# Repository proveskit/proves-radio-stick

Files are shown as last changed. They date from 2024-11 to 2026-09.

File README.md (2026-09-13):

# proves-radio-stick
New repo for working on a USB stick sized LoRa radio module. 

# Design Purpose
Being able to send and receive data using radios is one of the most fundemental functionalities of the satellite system. Right now, if we want to do anything with the radios we need to take a whole flight controller board out and get it setup to send and receive data. It would be nice to have an [RTL-SDR Style](https://www.rtl-sdr.com/buy-rtl-sdr-dvb-t-dongles/) USB dongle that can be used for testing and ground station purposes! 

# Design Requirements
- Employs an RP2040 Microcontroller (V0); RP2350 from V1 onward
- Onboard 3.3 V regulator for the microcontroller (LDO on V0, TPS62085 buck from V1); V2 radio runs from 5 V VBUS via ferrite
- Radio module: RFM9XW slot (V0), EByte E32-400M20S (V1), EByte E22-400M30S (V2)
- SMA Adaptor for the Antenna
- Is as comapct as possible 

# Versions
| Dir | MCU | Radio | Rail | Antenna | Notes |
|---|---|---|---|---|---|
| `provesradiostick_V0` | RP2040 | RFM9XW slot (SX127x) | 3V3 LDO | SMA | Original concept |
| `proves_radio_stick_V1` | RP2350 | EByte E32-400M20S (SX1278, 20 dBm) | 3V3 buck (TPS62085) | SMA | 4-layer 60 x 32.89 mm |
| `proves_radio_stick_V2` | RP2350 | EByte E22-400M30S (SX1268, 30 dBm) — same module as FC v5e | 3V3 buck + 5 V `RF_VCC` from VBUS via ferrite | SMA | 4-layer 80.5 x 32.89 mm; V1 stretched 20.5 mm to fit the 24 x 38.5 mm module |

## V2 radio pinout (RP2350 GPIO)
| E22 pin | Net | GPIO |
|---|---|---|
| NSS / SCK / MOSI / MISO | SPI1_CS0 / SPI1_SCK / SPI1_MOSI / SPI1_MISO | 9 / 10 / 11 / 8 |
| NRST | RF1_RST | 6 |
| BUSY | RF1_IO0 | 14 |
| DIO1 | RF1_IO1 | 15 |
| DIO2 | RF1_IO2 | 16 |
| RXEN / TXEN | RF1_RX_EN / RF1_TX_EN | 20 / 21 |
| VCC | RF_VCC (5 V, VBUS → FB1 → U19 TPS22918 load switch) | — |
| Radio power enable | RF_PWR_EN → U19 ON (10k pull-up to 3V3, default ON) | 18 |

V2 note: at 30 dBm the E22 draws ~650 mA peak on TX, above the 500 mA USB 2.0 default; use a USB 3 or high-current port for sustained TX. The 110 µF behind U19 soft-starts over ~3 ms (CT 1 nF, ~0.19 A inrush) so the host only sees ~11 µF at plug-in. Drive GPIO18 low then high to power-cycle the radio (hold NRST low and SPI lines low while off). V2 drops the 2.54 mm SWD pin header J1; use the JST-SH SWD connector J22. J3 screw terminal is sourced as Cixi Kefa KF128-2.54-10P (LCSC C474928), a 2.54 mm drop-in for the Phoenix MPT 0,5/10-2,54 footprint. J4 header and TP1–TP7 are not populated by JLC. Firmware differs from V1: SX1268 driver with BUSY handshake, not SX1278. Pin numbering differs from FC v5e (v5e uses SPI0 GPIO9-12, BUSY 13, DIO1 14, RXEN 22).

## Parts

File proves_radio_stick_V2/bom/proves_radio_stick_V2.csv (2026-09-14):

Ref | Value | Footprint | LCSC | Qty
C1,C2,C67,C70-C74,C76-C78 | 100n | Capacitor_SMD:C_0402_1005Metric | C1525 | 11
C3 | 47uF | Capacitor_SMD:C_0805_2012Metric | C16780 | 1
C4 | 100uF 10V | Capacitor_SMD:C_1210_3225Metric | C84455 | 1
C5,C15 | 10uF | Capacitor_SMD:C_0603_1608Metric | C19702 | 2
C6 | 100nF | Capacitor_SMD:C_0402_1005Metric | C1525 | 1
C7 | 100pF | Capacitor_SMD:C_0402_1005Metric | C1546 | 1
C14 | 22uF | Capacitor_SMD:C_0603_1608Metric | C59461 | 1
C63,C64 | 15p | Capacitor_SMD:C_0402_1005Metric | C1548 | 2
C65,C66 | 4.7u | RP2350_60QFN_minimal:C_0402_1005Metric_small_pads | C23733 | 2
C68,C69 | 4.7u | Capacitor_SMD:C_0402_1005Metric | C23733 | 2
C75 | 10u | Capacitor_SMD:C_0603_1608Metric | C19702 | 1
C79 | 1nF | Capacitor_SMD:C_0402_1005Metric | C1523 | 1
C80 | 1uF | Capacitor_SMD:C_0402_1005Metric | C52923 | 1
D1,D3 | LED | LED_SMD:LED_0603_1608Metric | C2290 | 2
D4 | NSR0320 | Diode_SMD:D_SOD-323F | C48192 | 1
FB1 | BLM21PG600SN1D | Inductor_SMD:L_0805_2012Metric | C18305 | 1
J2 | Conn_Coaxial | Connector_Coaxial:SMA_Amphenol_132134_Vertical | C3174425 | 1
J3 | Screw_Terminal_01x10 | TerminalBlock_Phoenix:TerminalBlock_Phoenix_MPT-0,5-10-2.54_1x10_P2.54mm_Horizontal | C474928 | 1
J12 | USB_C_Receptacle_USB2.0_16P | Connector_USB:USB_C_Receptacle_HRO_TYPE-C-31-M-12 | C165948 | 1
J22 | SWD Port | Connector_JST:JST_SH_BM03B-SRSS-TB_1x03-1MP_P1.00mm_Vertical | C160389 | 1
L1 | XFL4015-471MEC | easyeda2kicad:IND-SMD_L4.0-W4.0_XFL4020-102MEB | C18221164 | 1
L2 | 120nH | Inductor_SMD:L_0603_1608Metric | C86138 | 1
L3 | 3.3u | RP2350_60QFN_minimal:L_pol_2016 | C42411119 | 1
R1,R2,R5,R9,R11,R12,R39,R41,R95 | 10k | Resistor_SMD:R_0402_1005Metric | C25744 | 9
R3 | 162k | Resistor_SMD:R_0402_1005Metric | C54068 | 1
R4 | 510k | Resistor_SMD:R_0402_1005Metric | C11616 | 1
R7,R8 | 22 | Resistor_SMD:R_0402_1005Metric | C25092 | 2
R10,R13,R80,R93 | 1k | Resistor_SMD:R_0402_1005Metric | C11702 | 4
R14,R15 | 4.7k | Resistor_SMD:R_0402_1005Metric | C25900 | 2
R26,R27 | 5.1k | Resistor_SMD:R_0402_1005Metric | C25905 | 2
R94 | 33 | Resistor_SMD:R_0402_1005Metric | C25105 | 1
SW1,SW2 | KMR2 | FC_DEV_BOARD:BTN_KMR2_4.6X2.8 | C72443 | 2
U2 | TPS62085RLTT | easyeda2kicad:VSON-7_L2.0-W2.0-P0.5-TL | C2070694 | 1
U3 | E22-400M30S | easyeda2kicad:WIRELM-SMD_E22-400M30S | C411292 | 1
U11 | W25Q128JVS | Package_SO:SOIC-8_5.3x5.3mm_P1.27mm | C97521 | 1
U18 | RP2350_60QFN | RP2350_60QFN_minimal:RP2350-QFN-60-1EP_7x7_P0.4mm_EP3.4x3.4mm_ThermalVias | C42411118 | 1
U19 | TPS22918DBVR | Package_TO_SOT_SMD:SOT-23-6 | C131941 | 1
Y1 | ABM8-272-T3 | Crystal:Crystal_SMD_3225-4Pin_3.2x2.5mm | C20625731 | 1

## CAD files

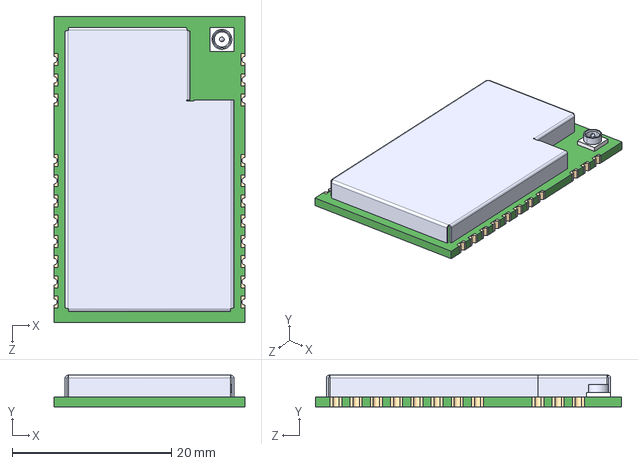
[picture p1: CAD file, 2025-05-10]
proves_radio_stick_V2/Backup_Footprints/E22-400M30S/E22-400M30S.step
24.0 x 3.97 x 38.5 mm

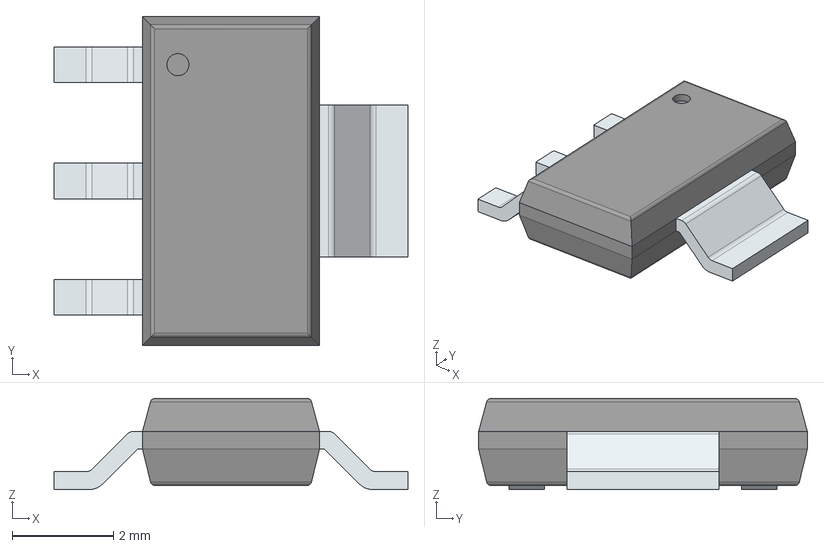
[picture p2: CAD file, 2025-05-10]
proves_radio_stick_V2/Backup_Footprints/LIB_AZ1117CH-3.3TRG1 (1)/AZ1117CH-3.3TRG1/3D/AZ1117CH-3.3TRG1.stp
7.00 x 6.50 x 1.80 mm
PinsArrayL
FilletPinR

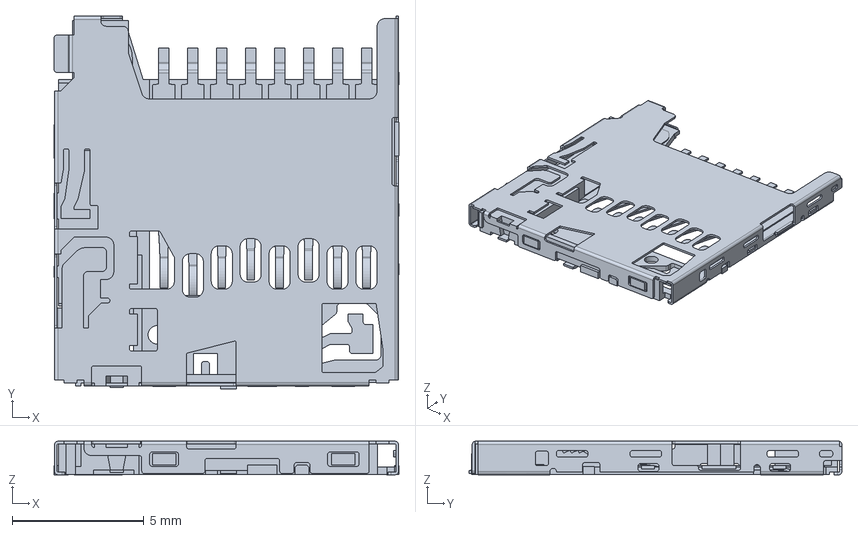
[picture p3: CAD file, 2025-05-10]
proves_radio_stick_V2/Backup_Footprints/Molex 503398-1892/503398-1892.stp
13.1 x 14.2 x 1.28 mm

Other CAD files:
proves_radio_stick_V2/Backup_Footprints/LIB_AZ1117CH-3.3TRG1 (1)/AZ1117CH-3.3TRG1/Allegro/sot230p700x180-4n.psm
proves_radio_stick_V2/Backup_Footprints/LIB_AZ1117CH-3.3TRG1 (1)/AZ1117CH-3.3TRG1/DEHDL/az1117ch_3.3trg1/chips/chips.prt

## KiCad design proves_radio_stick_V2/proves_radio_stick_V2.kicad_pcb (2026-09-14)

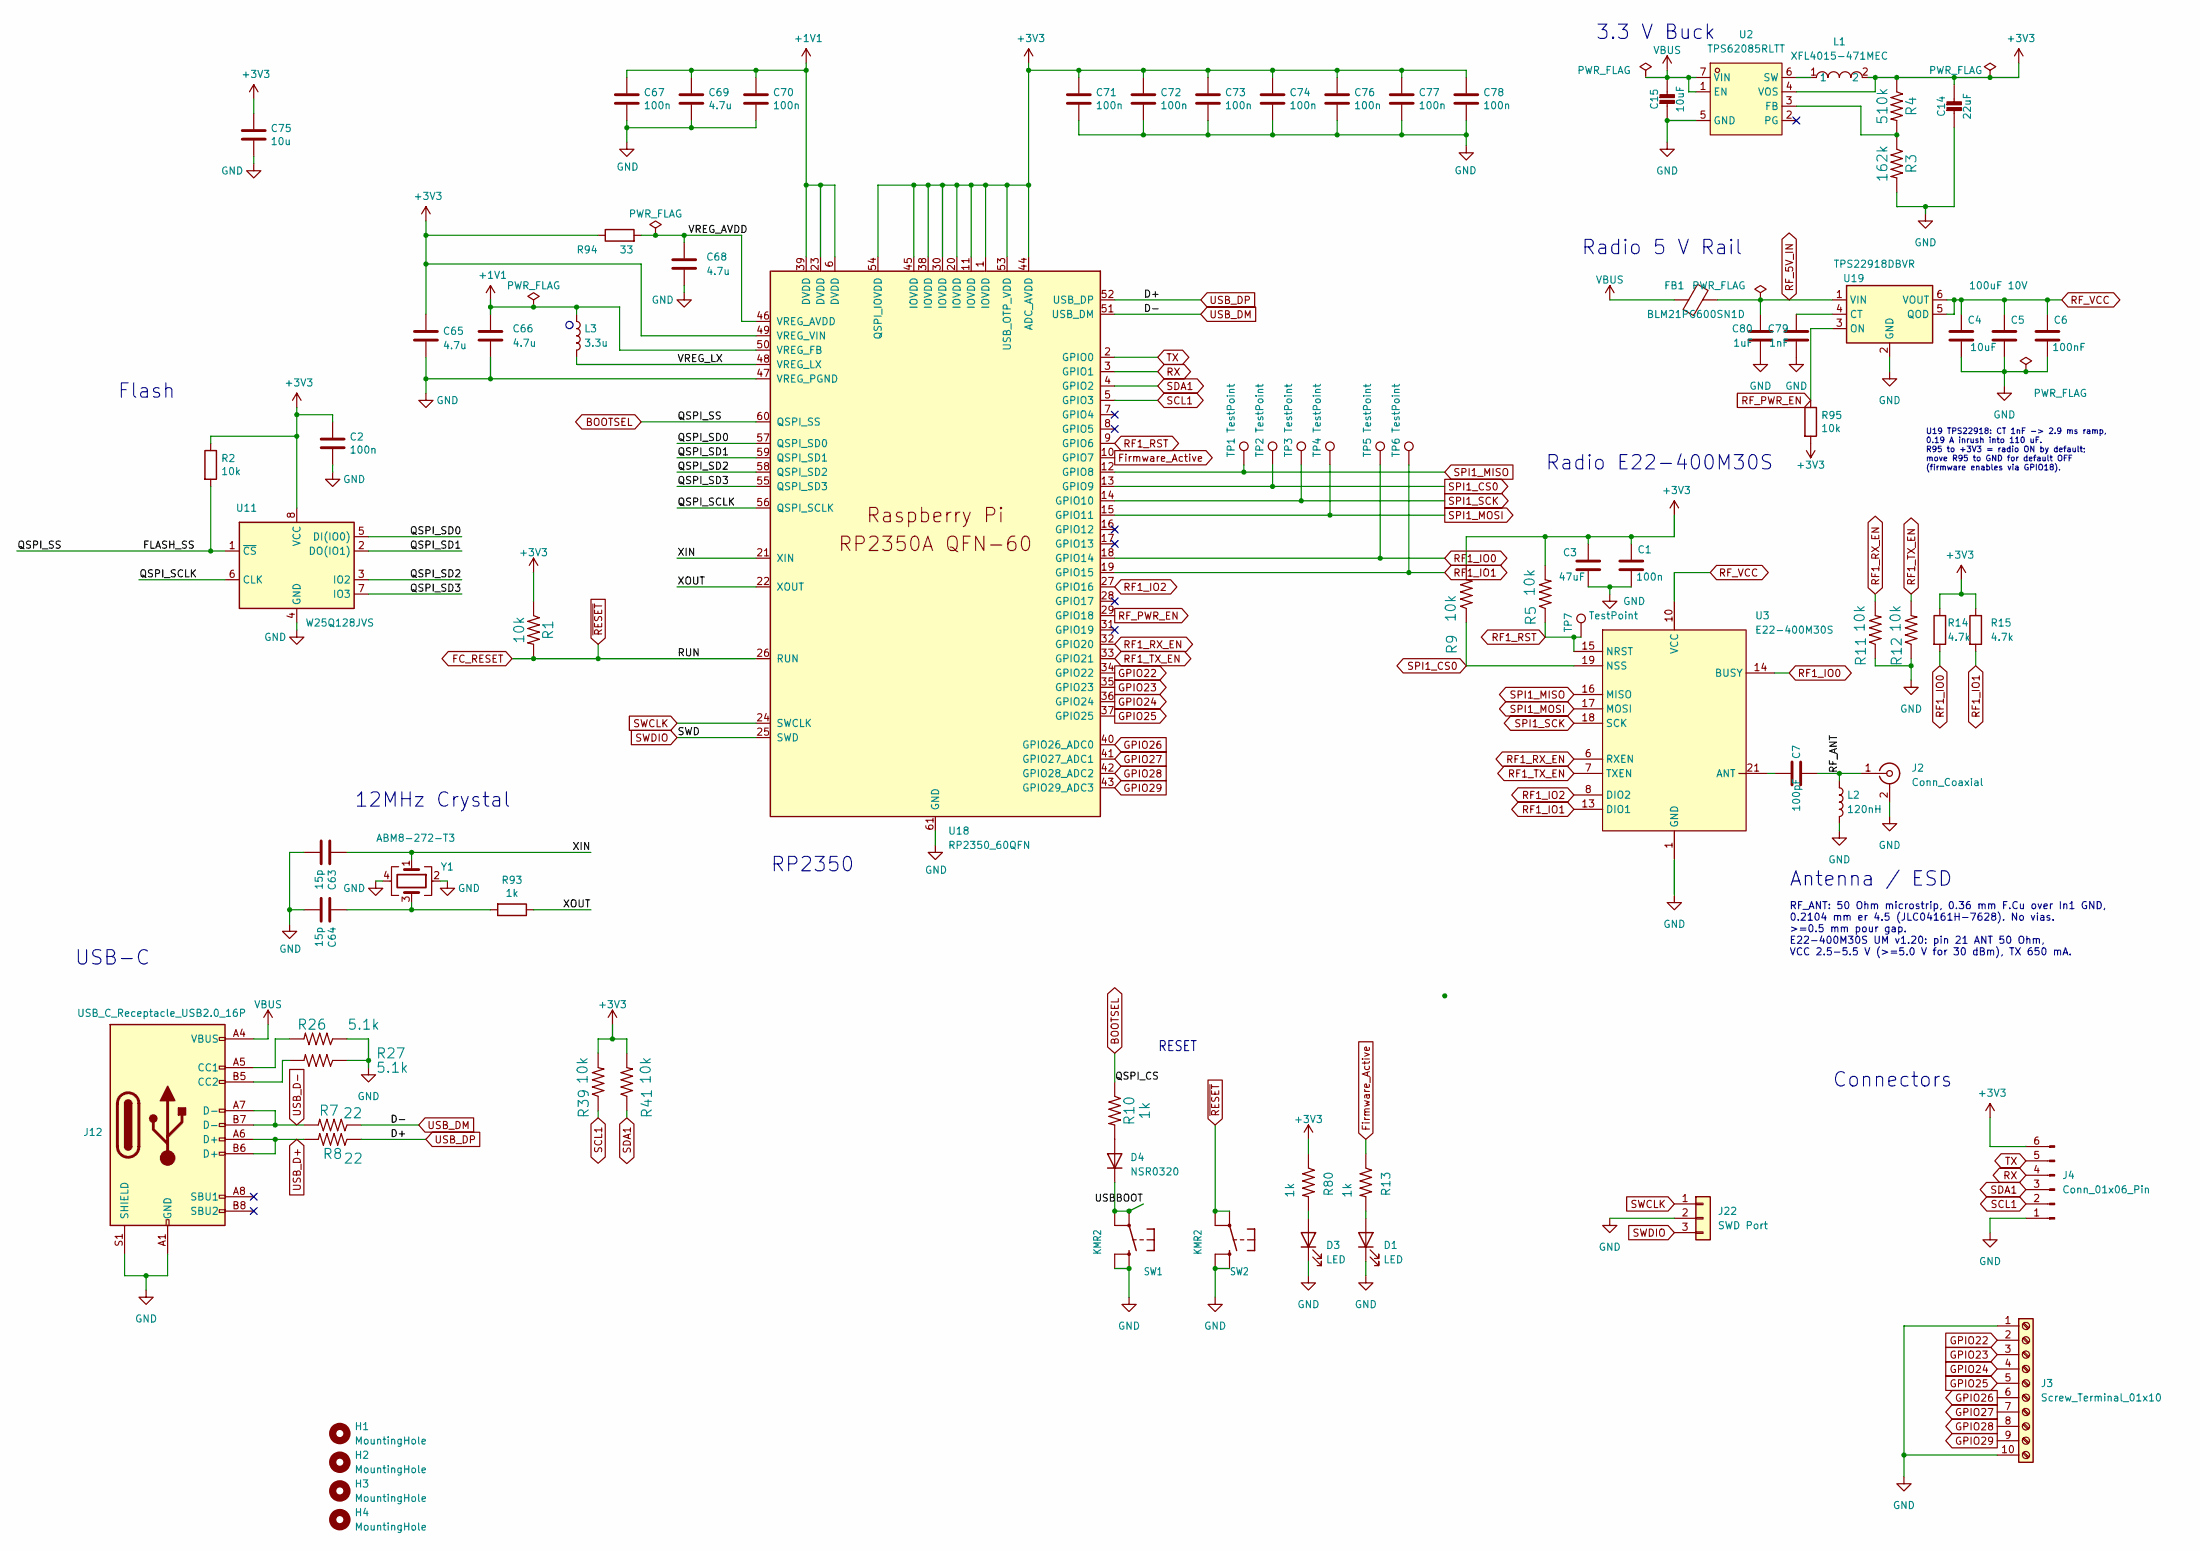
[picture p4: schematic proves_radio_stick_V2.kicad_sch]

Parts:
C1, C2, C67, C70, C71, C72, C73, C74, C76, C77, C78: 100n; C_0402_1005Metric; LCSC Part C1525
C3: 47uF; C_0805_2012Metric; LCSC Part C16780
C4: 100uF 10V; C_1210_3225Metric; LCSC Part C84455
C5, C15: 10uF; C_0603_1608Metric; LCSC Part C19702
C6: 100nF; C_0402_1005Metric; LCSC Part C1525
C7: 100pF; C_0402_1005Metric; LCSC Part C1546
C14: 22uF; C_0603_1608Metric; LCSC Part C59461
C63, C64: 15p; C_0402_1005Metric; LCSC Part C1548
C65, C66: 4.7u; C_0402_1005Metric_small_pads; LCSC Part C23733
C68, C69: 4.7u; C_0402_1005Metric; LCSC Part C23733
C75: 10u; C_0603_1608Metric; LCSC Part C19702
C79: 1nF; C_0402_1005Metric; LCSC Part C1523
C80: 1uF; C_0402_1005Metric; LCSC Part C52923
D1, D3: LED; LED_0603_1608Metric; LCSC Part C2290
D4: NSR0320; D_SOD-323F; LCSC Part C48192
FB1: BLM21PG600SN1D; L_0805_2012Metric; LCSC Part C18305
H1, H2, H3, H4: MountingHole; MountingHole_2.2mm_M2_Pad_TopBottom
J2: Conn_Coaxial; SMA_Amphenol_132134_Vertical; LCSC Part C3174425
J3: Screw_Terminal_01x10; TerminalBlock_Phoenix_MPT-0,5-10-2.54_1x10_P2.54mm_Horizont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; MPN KF128-2.54-10P; LCSC Part C474928
J4: Conn_01x06_Pin; PinHeader_1x06_P2.54mm_Vertical
J12: USB_C_Receptacle_USB2.0_16P; USB_C_Receptacle_HRO_TYPE-C-31-M-12; LCSC Part C165948
J22: SWD Port; JST_SH_BM03B-SRSS-TB_1x03-1MP_P1.00mm_Vertical; LCSC Part C160389
L1: XFL4015-471MEC; IND-SMD_L4.0-W4.0_XFL4020-102MEB; LCSC Part C18221164
L2: 120nH; L_0603_1608Metric; MPN LQW18ANR12G00D; LCSC Part C86138
L3: 3.3u; L_pol_2016; LCSC Part C42411119
R1, R2, R5, R9, R11, R12, R39, R41, R95: 10k; R_0402_1005Metric; LCSC Part C25744
R3: 162k; R_0402_1005Metric; LCSC Part C54068
R4: 510k; R_0402_1005Metric; LCSC Part C11616
R7, R8: 22; R_0402_1005Metric; LCSC Part C25092
R10, R13, R80, R93: 1k; R_0402_1005Metric; LCSC Part C11702
R14, R15: 4.7k; R_0402_1005Metric; LCSC Part C25900
R26, R27: 5.1k; R_0402_1005Metric; LCSC Part C25905
R94: 33; R_0402_1005Metric; LCSC Part C25105
SW1, SW2: KMR2; BTN_KMR2_4.6X2.8; LCSC Part C72443
TP1, TP2, TP3, TP4, TP5, TP6, TP7: TestPoint; TestPoint_Keystone_5000-5004_Miniature
U2: TPS62085RLTT; VSON-7_L2.0-W2.0-P0.5-TL; LCSC Part C2070694
U3: E22-400M30S; WIRELM-SMD_E22-400M30S; MPN E22-400M30S; LCSC Part C411292
U11: W25Q128JVS; SOIC-8_5.3x5.3mm_P1.27mm; LCSC Part C97521
U18: RP2350_60QFN; RP2350-QFN-60-1EP_7x7_P0.4mm_EP3.4x3.4mm_ThermalVias; LCSC Part C42411118
U19: TPS22918DBVR; SOT-23-6; LCSC Part C131941
Y1: ABM8-272-T3; Crystal_SMD_3225-4Pin_3.2x2.5mm; LCSC Part C20625731

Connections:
+1V1: C66.1, C67.1, C69.1, C70.1, L3.1, U18.6 (DVDD), U18.23 (DVDD), U18.39 (DVDD), U18.50 (VREG_FB)
+3V3: C1.1, C2.1, C3.1, C14.1, C65.1, C71.1, C72.1, C73.1, C74.1, C75.1, C76.1, C77.1, C78.1, J4.6, L1.2, R1.1, R2.1, R4.1, R5.2, R9.2, R14.1, R15.1, R39.2, R41.2, R80.1, R94.1, R95.2, U2.4 (VOS), U11.8 (VCC), U18.1 (IOVDD), U18.11 (IOVDD), U18.20 (IOVDD), U18.30 (IOVDD), U18.38 (IOVDD), U18.44 (ADC_AVDD), U18.45 (IOVDD), U18.49 (VREG_VIN), U18.53 (USB_OTP_VDD), U18.54 (QSPI_IOVDD)
/QSPI_SCLK: U11.6 (CLK), U18.56 (QSPI_SCLK)
/QSPI_SD0: U11.5 (DI(IO0)), U18.57 (QSPI_SD0)
/QSPI_SD1: U11.2 (DO(IO1)), U18.59 (QSPI_SD1)
/QSPI_SD2: U11.3 (IO2), U18.58 (QSPI_SD2)
/QSPI_SD3: U11.7 (IO3), U18.55 (QSPI_SD3)
/RF_ANT: C7.2, J2.1 (In), L2.1
/USBBOOT: D4.1 (K), SW1.A, SW1.A' (P1)
/VREG_AVDD: C68.1, R94.2, U18.46 (VREG_AVDD)
/VREG_LX: L3.2, U18.48 (VREG_LX)
/XIN: C63.1, U18.21 (XIN), Y1.1
/XOUT: R93.1, U18.22 (XOUT)
BOOTSEL: R2.2, R10.1, U11.1 (~CS), U18.60 (QSPI_SS)
FC_RESET: R1.2, SW2.A, SW2.A' (P1), U18.26 (RUN)
Firmware_Active: R13.1, U18.10 (GPIO7)
GND: C1.2, C2.2, C3.2, C4.2, C5.2, C6.2, C14.2, C15.2, C63.2, C64.2, C65.2, C66.2, C67.2, C68.2, C69.2, C70.2, C71.2, C72.2, C73.2, C74.2, C75.2, C76.2, C77.2, C78.2, C79.2, C80.2, D1.1 (K), D3.1 (K), J2.2 (Ext), J3.1, J3.10, J4.1, J12.A1 (GND), J12.A12 (GND), J12.B1 (GND), J12.B12 (GND), J12.S1 (SHIELD), J22.2, L2.2, R3.2, R11.1, R12.1, R26.1, R27.1, SW1.B (S), SW1.B' (S1), SW2.B (S), SW2.B' (S1), U2.5 (GND), U3.1 (GND), U3.2 (GND), U3.3 (GND), U3.4 (GND), U3.5 (GND), U3.11 (GND), U3.12 (GND), U3.20 (GND), U3.22 (GND), U11.4 (GND), U18.47 (VREG_PGND), U18.61 (GND), U19.2 (GND), Y1.2, Y1.4
GPIO22: J3.2, U18.34 (GPIO22)
GPIO23: J3.3, U18.35 (GPIO23)
GPIO24: J3.4, U18.36 (GPIO24)
GPIO25: J3.5, U18.37 (GPIO25)
GPIO26: J3.6, U18.40 (GPIO26_ADC0)
GPIO27: J3.7, U18.41 (GPIO27_ADC1)
GPIO28: J3.8, U18.42 (GPIO28_ADC2)
GPIO29: J3.9, U18.43 (GPIO29_ADC3)
unnamed: C64.1, R93.2, Y1.3
unnamed: D1.2 (A), R13.2
unnamed: D3.2 (A), R80.2
unnamed: D4.2 (A), R10.2
unnamed: J12.A5 (CC1), R26.2
unnamed: J12.B5 (CC2), R27.2
unnamed: R3.1, R4.2, U2.3 (FB)
unnamed: L1.1, U2.6 (SW)
unnamed: C7.1, U3.21 (ANT)
unnamed: C79.1, U19.4 (CT)
RF1_IO0: R14.2, TP5.1, U3.14 (BUSY), U18.18 (GPIO14)
RF1_IO1: R15.2, TP6.1, U3.13 (DIO1), U18.19 (GPIO15)
RF1_IO2: U3.8 (DIO2), U18.27 (GPIO16)
RF1_RST: R5.1, TP7.1, U3.15 (NRST), U18.9 (GPIO6)
RF1_RX_EN: R11.2, U3.6 (RXEN), U18.32 (GPIO20)
RF1_TX_EN: R12.2, U3.7 (TXEN), U18.33 (GPIO21)
RF_5V_IN: C80.1, FB1.2, U19.1 (VIN)
RF_PWR_EN: R95.1, U18.29 (GPIO18), U19.3 (ON)
RF_VCC: C4.1, C5.1, C6.1, U3.9 (VCC), U3.10 (VCC), U19.5 (QOD), U19.6 (VOUT)
RX: J4.4, U18.3 (GPIO1)
SCL1: J4.2, R39.1, U18.5 (GPIO3)
SDA1: J4.3, R41.1, U18.4 (GPIO2)
SPI1_CS0: R9.1, TP2.1, U3.19 (NSS), U18.13 (GPIO9)
SPI1_MISO: TP1.1, U3.16 (MISO), U18.12 (GPIO8)
SPI1_MOSI: TP4.1, U3.17 (MOSI), U18.15 (GPIO11)
SPI1_SCK: TP3.1, U3.18 (SCK), U18.14 (GPIO10)
SWCLK: J22.1, U18.24 (SWCLK)
SWDIO: J22.3, U18.25 (SWD)
TX: J4.5, U18.2 (GPIO0)
USB_D+: J12.A6 (D+), J12.B6 (D+), R8.2
USB_D-: J12.A7 (D-), J12.B7 (D-), R7.2
USB_DM: R7.1, U18.51 (USB_DM)
USB_DP: R8.1, U18.52 (USB_DP)
VBUS: C15.1, FB1.1, J12.A4 (VBUS), J12.A9 (VBUS), J12.B4 (VBUS), J12.B9 (VBUS), U2.1 (EN), U2.7 (VIN)

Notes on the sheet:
RESET
Flash
12MHz Crystal
RF_ANT: 50 Ohm microstrip, 0.36 mm F.Cu over In1 GND, 0.2104 mm er 4.5 (JLC04161H-7628). No vias. >=0.5 mm pour gap. E22-400M30S UM v1.20: pin 21 ANT 50 Ohm, VCC 2.5-5.5 V (>=5.0 V for 30 dBm), TX 650 mA.
U19 TPS22918: CT 1nF -> 2.9 ms ramp, 0.19 A inrush into 110 uF. R95 to +3V3 = radio ON by default; move R95 to GND for default OFF (firmware enables via GPIO18).
3.3 V Buck
Radio 5 V Rail
Radio E22-400M30S
Antenna / ESD
Connectors
USB-C
RP2350

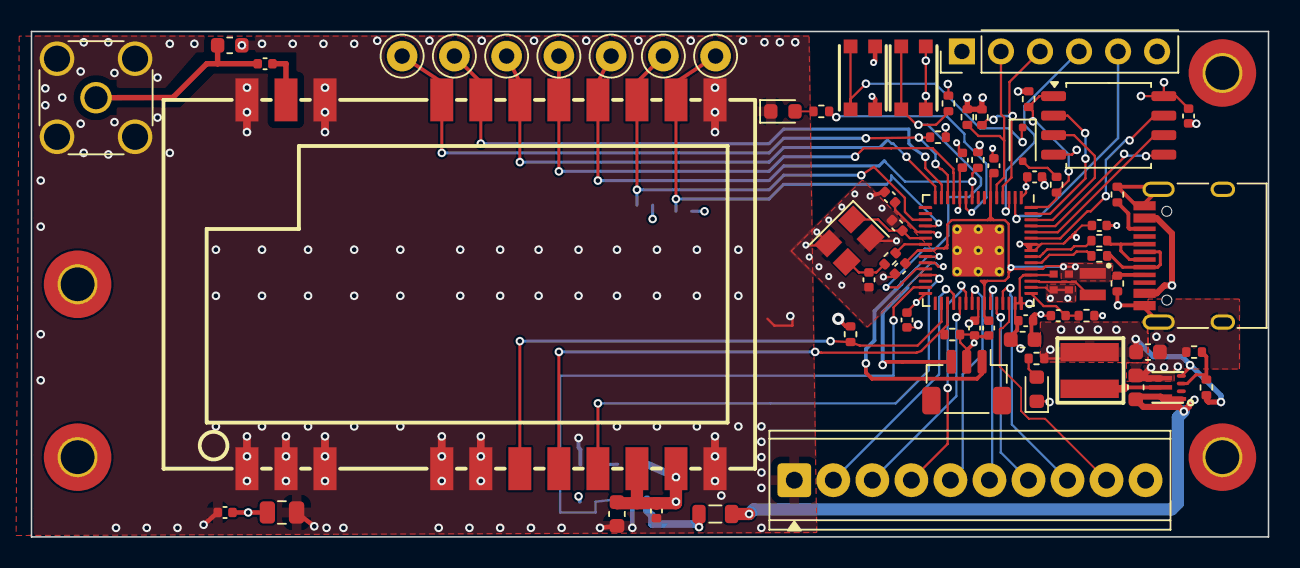
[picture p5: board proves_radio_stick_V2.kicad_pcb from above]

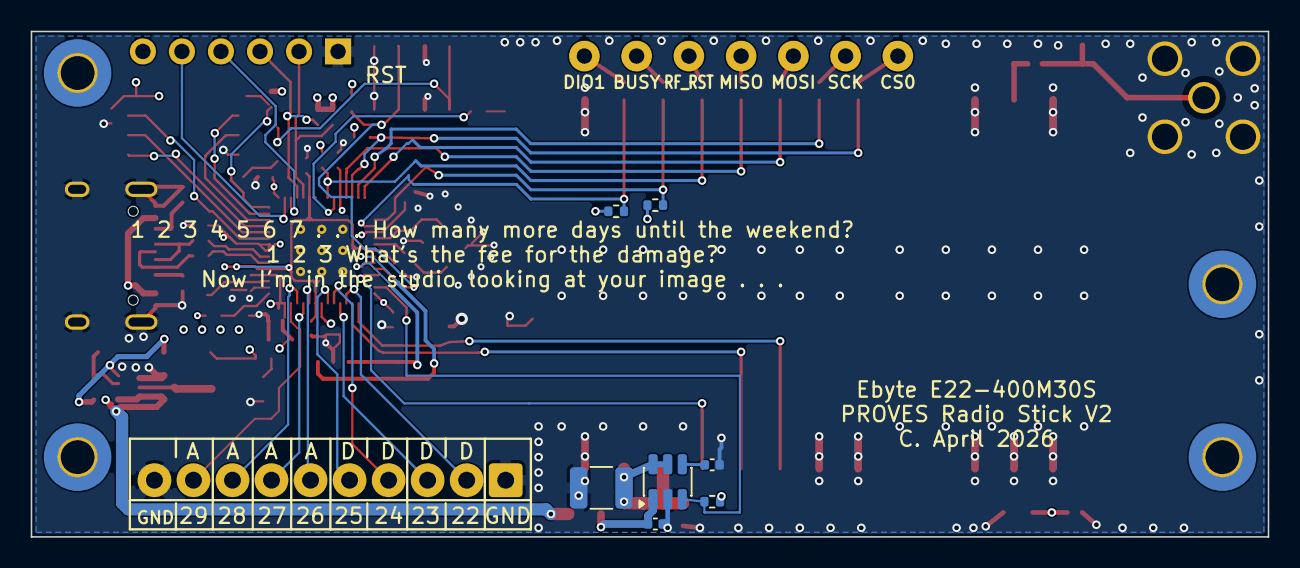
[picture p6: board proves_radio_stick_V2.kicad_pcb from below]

Board: 4 copper layers, 80.5 x 32.9 mm, 80 parts (7 on the bottom side), 59 nets.

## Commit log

2025-03-18 Created V0a Project
    [proves_radio_stick_V0a.kicad_pcb, proves_radio_stick_V0a.kicad_sch]
2025-05-09 Removed Unused Files
    [provesradiostick_V0.kicad_sch]
2025-05-10 Created Radio Stick V1 Project
    [503398-1892.stp, AZ1117CH-3.3TRG1.SchLib, AZ1117CH-3.3TRG1.stp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]
2025-06-15 Removed V0a Project
    [proves_radio_stick_V0a.kicad_pcb, proves_radio_stick_V0a.kicad_sch, proves_radio_stick_V1.kicad_pcb]
2025-10-04 Added E22-400M
    [proves_radio_stick_V1.kicad_sch]
2025-10-05 Initial TPS62 Layout
    [proves_radio_stick_V1.kicad_pcb, proves_radio_stick_V1.kicad_sch]
2025-10-05 Removed 3v3 Linear Regulator
    [proves_radio_stick_V1.kicad_pcb, proves_radio_stick_V1.kicad_sch]
2026-04-17 RP2350 and Support Circuits Layout
    [proves_radio_stick_V1.kicad_pcb, proves_radio_stick_V1.kicad_sch]
2026-04-17 Added E32 Footprint
    [proves_radio_stick_V1.kicad_pcb, proves_radio_stick_V1.kicad_sch]
2026-04-17 Initial Layout Complete
    [proves_radio_stick_V1.kicad_pcb, proves_radio_stick_V1.kicad_sch]
2026-04-17 Initial Production Files
    [proves_radio_stick_V1-CuBottom.gbr, proves_radio_stick_V1-CuIn1.gbr, proves_radio_stick_V1-CuIn2.gbr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]
2026-04-17 Updated DRC
    [proves_radio_stick_V1.kicad_pcb]
2026-04-21 Updated with Screw Terminals and Vias
    [proves_radio_stick_V1-CuBottom.gbr, proves_radio_stick_V1-CuIn1.gbr, proves_radio_stick_V1-CuIn2.gbr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]
2026-04-21 Updated Prod Files
    [proves_radio_stick_V1-CuBottom.gbr, proves_radio_stick_V1-CuIn1.gbr, proves_radio_stick_V1-CuIn2.gbr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]
2026-09-13 Create proves_radio_stick_V2 with EByte E22-400M30S
    V1 layout with the radio swapped to the E22-400M30S (SX1268, 30 dBm),
    the same module used on FC v5e. Board stretched to 80.5 x 32.89 mm to
    fit the 24 x 38.5 mm module.
    - New 5 V RF_VCC rail: VBUS -> FB1 -> 100u/10u/100n at module VCC pads
    - BUSY on GPIO14, DIO1 GPIO15, DIO2 GPIO16; SPI1/RST/RXEN/TXEN as V1
    - RF: 0.36 mm 50 ohm microstrip, RF netclass, ESD shunt L2 + DC block C7
    - Grounding: solid pad connects, in-pad vias, launch fence, B.Cu pour
    - easyeda2kicad symbols/footprints/3D now project-local
    - JLC production files with paste layers and filled zones
    - README: versions table, V2 pinout, USB current note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
    [503398-1892.stp, AZ1117CH-3.3TRG1.SchLib, AZ1117CH-3.3TRG1.stp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]
2026-09-13 V2: add TPS22918 soft-start switch on RF_VCC, drop J1
    Limits USB plug-in inrush: the 110 uF radio bulk now sits behind U19
    (CT 1 nF, ~2.9 ms ramp, ~0.19 A peak) so the host sees ~11 uF. GPIO18
    drives the enable via RF_PWR_EN; R95 10k to 3V3 keeps the radio on by
    default. Removed the 2.54 mm SWD header J1 (duplicate of JST J22) to
    free routing for the enable line.
    Claude-Session: https://claude.ai/code/session_01N2AhKET2rgFbanw1Dr874g
    [BOM-proves_radio_stick_V2.csv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]
2026-09-13 V2: burn down ERC/DRC and schematic-parity items
    ERC 4 errors -> 0 (no_connects on GPIO4/5/12/13), warnings 110 -> 45.
    DRC 67 -> 48, all remaining are cached-library mismatches; parity 57 -> 0.
    Retyped EasyEDA symbol pins, refreshed GND/LED cached symbols, cleared
    silk-over-copper and edge items without moving copper, removed a
    dangling +1V1 stub and off-board silk text, synced Description and
    Datasheet fields, fixed C3/H2-H4 footprint links and R26/R27 BOM flag.
    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
    [proves_radio_stick_V2-B_Cu.gbl, proves_radio_stick_V2-B_Mask.gbs, proves_radio_stick_V2-B_Paste.gbp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]
2026-09-13 V2: replace eagle-import power symbols with power:VBUS/+3V3
    Six V0-era eagle power symbols swapped for KiCad standard ones, placed
    so each pin lands on the existing wire end; netlist byte-identical.
    Also removed three local labels that duplicated global SWCLK/~RESET.
    ERC warnings 45 -> 31, still 0 errors.
    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
    [proves_radio_stick_V2.kicad_sch]
2026-09-13 V2: source J3 terminal block, DNP J4/TP1-7, prune dead lib rows
    J3 gets LCSC C474928 (Cixi Kefa KF128-2.54-10P, drop-in for the Phoenix
    MPT 0,5/10-2,54 footprint, 1.1 mm drills). J4 header and TP1-TP7 marked
    exclude-from-BOM so schematic, BOM and CPL agree. Removed lib-table rows
    pointing at directories that no longer exist. Production files
    regenerated from this state.
    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
    [BOM-proves_radio_stick_V2.csv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]
2026-09-14 V2: rearrange schematic right half for readability
    Buck, radio 5 V rail, radio, antenna/ESD and connector blocks moved
    into three rows with section titles; overlapping reference, value,
    PWR_FLAG and note text separated. Rigid block moves only; netlist
    identical to previous commit.
    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
    [proves_radio_stick_V2.kicad_sch]
2026-09-14 V2: JLCPCB parts database and LCSC fields on every part
    Adds jlcpcb/project.db for the kicad-jlcpcb-tools plugin (81 rows, live
    stock), LCSC Part on all 52 previously blank symbols and footprints,
    exclude-from-pos on the hand-fit J4/TP1-7, and moves C4 to C84455
    (Murata GRM32ER61A107ME20L, a true 1210 10 V part; C15008 is 1206
    6.3 V per JLC). Board and project files are now in KiCad 10 format
    after a GUI save.
    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
    [BOM-proves_radio_stick_V2.csv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]
